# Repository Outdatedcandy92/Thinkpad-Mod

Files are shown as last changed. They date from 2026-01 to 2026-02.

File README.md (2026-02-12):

# Thinkpad Mod

A small board that I designed to be embedded inside my Thinkpad X1 Carbon Gen 7 laptop. It features a MCU on board along with a ton of sensors for data logging and an RGB led placed to shine on the red dot that's on the Thinkpad Logo.



---
## Schematic

The project's KiCad files can be found under `/PCB/kicad`.



---
## PCB



---
## BOM

| Name | Description | Quantity | Price  | Shipping |
| --- | --- | --- | --- | --- |
| Componenets | Componenets from LCSC. detailed part breakdown [here](./production/Thinkpad_Mod_Rev_1.0.0_bom.csv) | - | $26.63 | $12.62 |
| PCB+Stencil | PCB and Stencil from JLCPCB | - | $5.10  | $8.35 |
| **Sub Total** | | | $31.73 | $20.97 |
| **Total** | | | $52.7  | |

---

## License

This project is licensed under the CERN Open Hardware Licence Version 2 Weakly Reciprocal [(CERN OHL W)](LICENSE.txt)

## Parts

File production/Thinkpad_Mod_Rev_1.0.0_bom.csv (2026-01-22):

Reference | Qty | Value | Footprint | LCSC Part
C1,C5,C6,C10,C11,C13,C14 | 7 | 100nF | Capacitor_SMD:C_0402_1005Metric | C1525
C2,C3,C4,C7,C8,C9 | 6 | 1uF | Capacitor_SMD:C_0402_1005Metric | C52923
C12 | 1 | 220nF | Capacitor_SMD:C_0402_1005Metric | C16772
C15 | 1 | 10uF | Capacitor_SMD:C_0402_1005Metric | C315248
D1,D2 | 2 | BAT54L-TP | Diode_SMD:D_SOD-882 | C587155
J1 | 1 | USB | easyeda2kicad:CONN-SMD_4P-P1.00_SM04B-SRSS-TB-LF-SN | C160404
J2 | 1 | Conn_01x02_Socket | easyeda2kicad:CONN-SMD_2P-P1.00_SM02B-SRSS-TB-LF-SN | C160402
LED1 | 1 | XL-3806RGBC-4L | easyeda2kicad:LED-SMD_4P-L3.8-W1.0_XL-3806RGBC-4L | C2843779
M1 | 1 | Vibration Motor | easyeda2kicad:CONN-SMD_2P-P1.00_SM02B-SRSS-TB-LF-SN | C160402
Q1 | 1 | NMOS | Package_TO_SOT_SMD:SOT-23 | C10488
R1,R5 | 2 | 10K | Resistor_SMD:R_0402_1005Metric | C25128
R2,R3,R4 | 3 | 470 | Resistor_SMD:R_0402_1005Metric | C25900
R6,R9,R12,R13,R14 | 5 | 5K | Resistor_SMD:R_0402_1005Metric | C25905
R7 | 1 | 220 | Resistor_SMD:R_0402_1005Metric | C25091
SW1 | 1 | SW_Push | Resistor_SMD:R_0805_2012Metric | -
SW2 | 1 | Vibration Sensor (NO switch) | Resistor_SMD:R_0805_2012Metric | C42371121
U1 | 1 | ATSAMD21E18A-M | Package_DFN_QFN:QFN-32-1EP_5x5mm_P0.5mm_EP3.6x3.6mm | C2052801
U2 | 1 | TLV75533PDQNR | easyeda2kicad:X2SON-4_L1.0-W1.0-P0.65-TL-EP | C2861882
U3 | 1 | TMP112xxDRL | Package_TO_SOT_SMD:SOT-563 | C28927
U4 | 1 | TMAG5273A1QDBVR | easyeda2kicad:SOT-23-6_L2.9-W1.6-P0.95-LS2.8-BR | C3716049
U5 | 1 | LSM303AGRTR | easyeda2kicad:LGA-12_L2.0-W2.0-P0.50-BL | C126671

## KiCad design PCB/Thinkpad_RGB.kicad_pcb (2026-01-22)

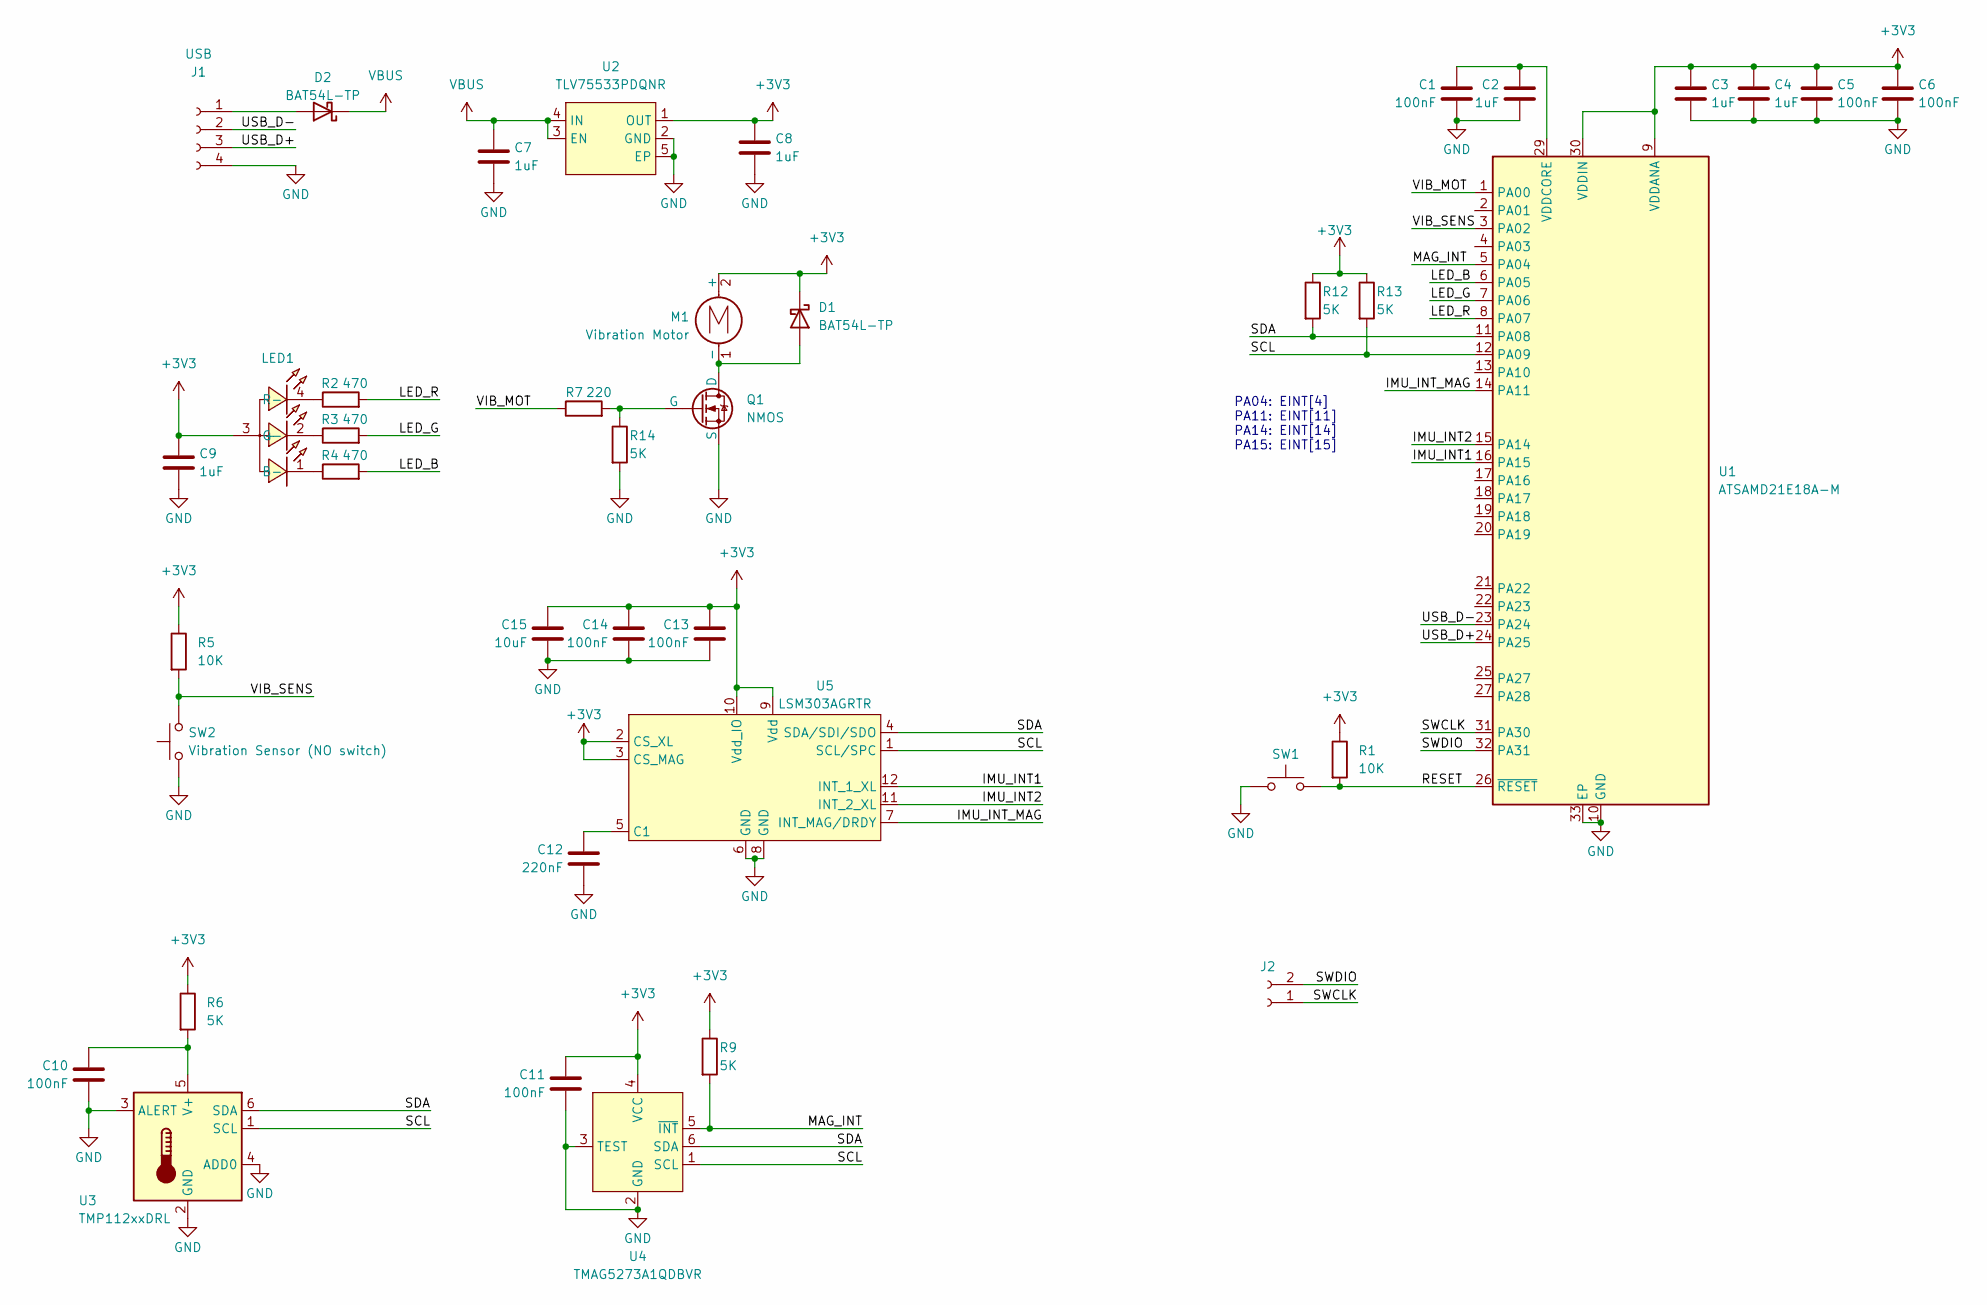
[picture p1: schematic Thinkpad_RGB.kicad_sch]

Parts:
C1, C5, C6, C10, C11, C13, C14: 100nF; C_0402_1005Metric; LCSC Part C1525
C2, C3, C4, C7, C8, C9: 1uF; C_0402_1005Metric; LCSC Part C52923
C12: 220nF; C_0402_1005Metric; LCSC Part C16772
C15: 10uF; C_0402_1005Metric; LCSC Part C315248
D1, D2: BAT54L-TP; D_SOD-882; LCSC Part C587155
J1: USB; CONN-SMD_4P-P1.00_SM04B-SRSS-TB-LF-SN; LCSC Part C160404
J2: Conn_01x02_Socket; CONN-SMD_2P-P1.00_SM02B-SRSS-TB-LF-SN; LCSC Part C160402
LED1: XL-3806RGBC-4L; LED-SMD_4P-L3.8-W1.0_XL-3806RGBC-4L; LCSC Part C2843779
M1: Vibration Motor; CONN-SMD_2P-P1.00_SM02B-SRSS-TB-LF-SN; LCSC Part C160402
Q1: NMOS; SOT-23; LCSC Part C10488
R1, R5: 10K; R_0402_1005Metric; LCSC Part C25128
R2, R3, R4: 470; R_0402_1005Metric; LCSC Part C25900
R6, R9, R12, R13, R14: 5K; R_0402_1005Metric; LCSC Part C25905
R7: 220; R_0402_1005Metric; LCSC Part C25091
SW1: SW_Push; R_0805_2012Metric
SW2: Vibration Sensor (NO switch); R_0805_2012Metric; LCSC Part C42371121
U1: ATSAMD21E18A-M; QFN-32-1EP_5x5mm_P0.5mm_EP3.6x3.6mm; LCSC Part C2052801
U2: TLV75533PDQNR; X2SON-4_L1.0-W1.0-P0.65-TL-EP; LCSC Part C2861882
U3: TMP112xxDRL; SOT-563; LCSC Part C28927
U4: TMAG5273A1QDBVR; SOT-23-6_L2.9-W1.6-P0.95-LS2.8-BR; LCSC Part C3716049
U5: LSM303AGRTR; LGA-12_L2.0-W2.0-P0.50-BL; LCSC Part C126671

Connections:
+3V3: C3.1, C4.1, C5.1, C6.1, C8.1, C9.1, C11.1, C13.1, C14.1, C15.1, D1.1 (K), LED1.3 (+), M1.2 (+), R1.1, R5.1, R6.1, R9.1, R12.1, R13.1, U1.9 (VDDANA), U1.30 (VDDIN), U2.1 (OUT), U4.4 (VCC), U5.2 (CS_XL), U5.3 (CS_MAG), U5.9 (Vdd), U5.10 (Vdd_IO)
/IMU_INT1: U1.16 (PA15), U5.12 (INT_1_XL)
/IMU_INT2: U1.15 (PA14), U5.11 (INT_2_XL)
/IMU_INT_MAG: U1.14 (PA11), U5.7 (INT_MAG/DRDY)
/LED_B: R4.2, U1.6 (PA05)
/LED_G: R3.2, U1.7 (PA06)
/LED_R: R2.2, U1.8 (PA07)
/MAG_INT: R9.2, U1.5 (PA04), U4.5 (~INT)
/RESET: R1.2, SW1.2, U1.26 (~RESET)
/SCL: R13.2, U1.12 (PA09), U3.1 (SCL), U4.1 (SCL), U5.1 (SCL/SPC)
/SDA: R12.2, U1.11 (PA08), U3.6 (SDA), U4.6 (SDA), U5.4 (SDA/SDI/SDO)
/SWCLK: J2.1, U1.31 (PA30)
/SWDIO: J2.2, U1.32 (PA31)
/USB_D+: J1.3, U1.24 (PA25)
/USB_D-: J1.2, U1.23 (PA24)
/VIB_MOT: R7.1, U1.1 (PA00)
/VIB_SENS: R5.2, SW2.2, U1.3 (PA02)
GND: C1.2, C2.2, C3.2, C4.2, C5.2, C6.2, C7.2, C8.2, C9.2, C10.2, C11.2, C12.2, C13.2, C14.2, C15.2, J1.4, Q1.3 (S), R14.2, SW1.1, SW2.1, U1.10 (GND), U1.28 (GND), U1.33 (EP), U2.2 (GND), U2.5 (EP), U3.2 (GND), U3.3 (ALERT), U3.4 (ADD0), U4.2 (GND), U4.3 (TEST), U5.6 (GND), U5.8 (GND)
unnamed: D1.2 (A), M1.1 (-), Q1.1 (D)
unnamed: D2.2 (A), J1.1
unnamed: LED1.1 (B-), R4.1
unnamed: LED1.2 (G-), R3.1
unnamed: LED1.4 (R-), R2.1
unnamed: Q1.2 (G), R7.2, R14.1
unnamed: C1.1, C2.1, U1.29 (VDDCORE)
unnamed: C10.1, R6.2, U3.5 (V+)
unnamed: C12.1, U5.5 (C1)
VBUS: C7.1, D2.1 (K), U2.3 (EN), U2.4 (IN)

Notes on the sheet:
PA04: EINT[4] PA11: EINT[11] PA14: EINT[14] PA15: EINT[15]

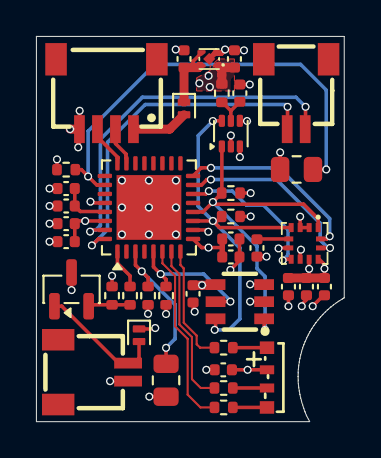
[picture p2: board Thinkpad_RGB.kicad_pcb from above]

Board: 4 copper layers, 17.1 x 21.4 mm, 40 parts (0 on the bottom side), 28 nets.

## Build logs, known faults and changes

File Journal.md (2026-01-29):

# 15/01/26 - 16/01/26

I own a Thinkpad X1 Carbon Gen 7 laptop and I just love opening it up and admiring the internals. It's quite possible the best laptop I've even owned, and its so organized and thoughtfully designed, It's got captive screws for the back cover and everything on the inside is nicely laid out.

Here's a picture of how it looks on the inside.



Now something I've noticed is that this Thinkpad has a lot of empty space, especially right under the battery when you remove it.



That got me thinking. What if I put embed something inside my laptop. I thought a lot about it and was kind of lost on what to embed inside. But then I noticed the red circle inside, and I realized that it was actually the red dot on the thinkpad logo on my laptop.



I wondered if I could somehow get the red dot to glow, to test my theory I took a flashlight and shined it on the big red dot on the inside and sure enough you could see the red dot glow.
This gave me a nice idea, what I basically make a tiny PCB that has a RGB light and then I could basically make the red dot on the thinkpad glow.

And so I began my journey for this project. I first took a picture of the insides and brought it in figma and drew dimensions using the values I measured from my calipers.



And looking back this was pretty much a waste of time because I had to manually measure so many things, and in the end I couldn't even export it as a DXF so I couldn't even use it in kicad later on. But this is what my measurements looked like.



Since I couldn't really use this I went on fusion360 and imported this image, calibrated it and drew some outlines which I could export and use as guidelines for my PCB later.



After exporting this as a DXF I hopped on KiCad and started drawing up a schematic.

Now for the actual PCB I wanted a tiny board with a MCU and an RGB LED so I began searching for some suitable ICs to use. In the end I decided to go with an ATSAMD21, as it's a very tiny QFN MCU that barely needs any supporting circuitry + It does crystal less USB. 

For my RGB LED I decided to go with a right angle LED (I think that's what they are called), instead of shooting light up or down, it shoots it sideways. This was good for me because that meant I could place the LED right next to the red dot.

Now that was pretty much it for what I initially wanted to achieve, but I thought to myself, if I'm gonna embed a PCB inside my laptop why not pack it full of sensors. So that's exactly what I did.

I searched up and added quite a few small sensors on the board. For most of my sensors I went with sensors that had I2C so I could save GPIO and more importantly keep routing easier.

All in all I added a temperature sensor, a magnet sensor, an IMU and finally a vibration sensor.



All of them used I2C except for the vibration sensor, which I hooked up to an analog capable pin on my MCU.

I additionally also decided to add a vibration motor just so I could get some haptic feedback. Implementing this was not very straightforward. Even though a motor is just a 2 terminal device, I can't just hook it up to a MCU pin directly and control it as it requires a lot of current, which would straight up fry the MCU. 
The solution to this problem would be to basically have the MCU control a switch that turns power on/off to the motor, and that's where MOSFETs come in. A MOSFET is basically a voltage controlled switch, and it gives you the ability to switch on/off large things with small input (not really a good description). But anyways I implemented what's known as a low side switch with an NMOS FET.



When the VIB_MOT goes high the switch basically closes and the motor is connected to ground and current can flow through it and the motor can run. And similarly when the VIB_MOT goes low (by default it's in a low state because we added a pull down resistor) the switch is off and the motor is not connected to ground, ie- current can flow through it and it wont run.
Since a motor is an inductive load (meaning it stores energy in magnetic fields), when its disconnected from ground it can suddenly output a lot of voltage in the reverse polarity, and that can potentially fry our MOSFET, to solve this we add a diode in parallel, so when it's disconnected that voltage can flow through the diode and not damage our FET.

Now after finishing all this up I added a USB port and a small LDO on board, and then moved onto assigning footprints. I went of 0402s for my passives and for my motor, USB and debug headers I went with JST_SH SMD connectors. SH series is the second smallest JST connectors you can get (atleast on lcsc I think), its 1.0mm pitch headers and are basically prefect for my use case.

This is what my finished schematic looked like:



## Time Spent: 4 Hours

# 17/01/26 

I started working on the PCB and the first thing I did was import the DXF I made in Fusion360 to basically get a visual idea of how I should layout my components.



I placed the LED right next to the red dot, and then made the USB port face the way of my laptop's internal USB board. I plan on physically soldering wires on my USB port from the inside and then hooking it up to my PCB. 

Now fast forward a few hours and this is what I ended up with



it's a very beautifully lay-ed out board and I did my best to route it nicely. I went with a 4 layer board with a SIG/GND/PWR/SIG stackup and did my best to route most of my signals on the top layer with a solid ground reference.

This is how I kind of plan to place it inside my laptop



## Time Spent: 3 Hours

## 21/01/26

Since I was done with the PCB I went over back to my schematic editor and assigned every component an LCSC ID (it was a pretty dreadful task). And once again I was lost in the JST naming convention and had a hard time finding the appropriate housing and crimp for the connectors.
But I kinda figured it out this time, I realized that for every JST series they have a part number of the housing, crimp and headers in the datasheet. 

After this I went back into the PCB editor and fixed up like a bajillion DRC errors, most of them were thrown because my components were too close to the edge, I changed up my DRC values to be more in line with my PCB fab's rules and most of my DRC errors went away, and for the remaining few I manually fixed them.

I went ahead and uploaded my component list and Gerber to get price quotes for my BOM. And after that I started working on setting up the repository for this project, added everything in a folder and wrote a README and then pushed it all to GitHub. While I was here I also took the time to download and assign 3D models to my footprints so I could get a cool screenshot of the render!



## Time Spent: 1.5 Hours

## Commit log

2026-01-22 rev 1
    [Thinkpad_Mod_Rev_1.0.0_bom.csv, Thinkpad_Mod_Rev_1.0.0_designators.csv, Thinkpad_Mod_Rev_1.0.0_positions.csv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]
2026-02-12 bom readme
